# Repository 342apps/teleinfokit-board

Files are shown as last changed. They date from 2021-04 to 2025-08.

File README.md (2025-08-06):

# teleinfokit-board

## Firmware TeleInfoKit

Ce repo comprend les fichiers source Eagle, schema et PCB pour le module de collecte de tele-information [Teleinfokit](https://342apps.net/module-teleinfokit/) associé à son [firmware dédié](https://github.com/342apps/teleinfokit).

Ce module permet de récupérer les données de consommation électrique grâce aux données de télé-information du bus TIC des compteurs électriques français et d'exploiter ces données dans une application de domotique telle que Home Assistant.

## Compatibilité avec ESPHome

Ce module est également compatible avec un firmware généré par [ESPHome](https://esphome.io/) pour une integration dans Home Assistant. 

Le fichier de configuration compatible avec ce module ainsi que toute la documentation est disponible dans le dossier [esphome](./esphome/). Ce firmware offre cependant moins de fonctionnalités que le firmware natif.

## PCB

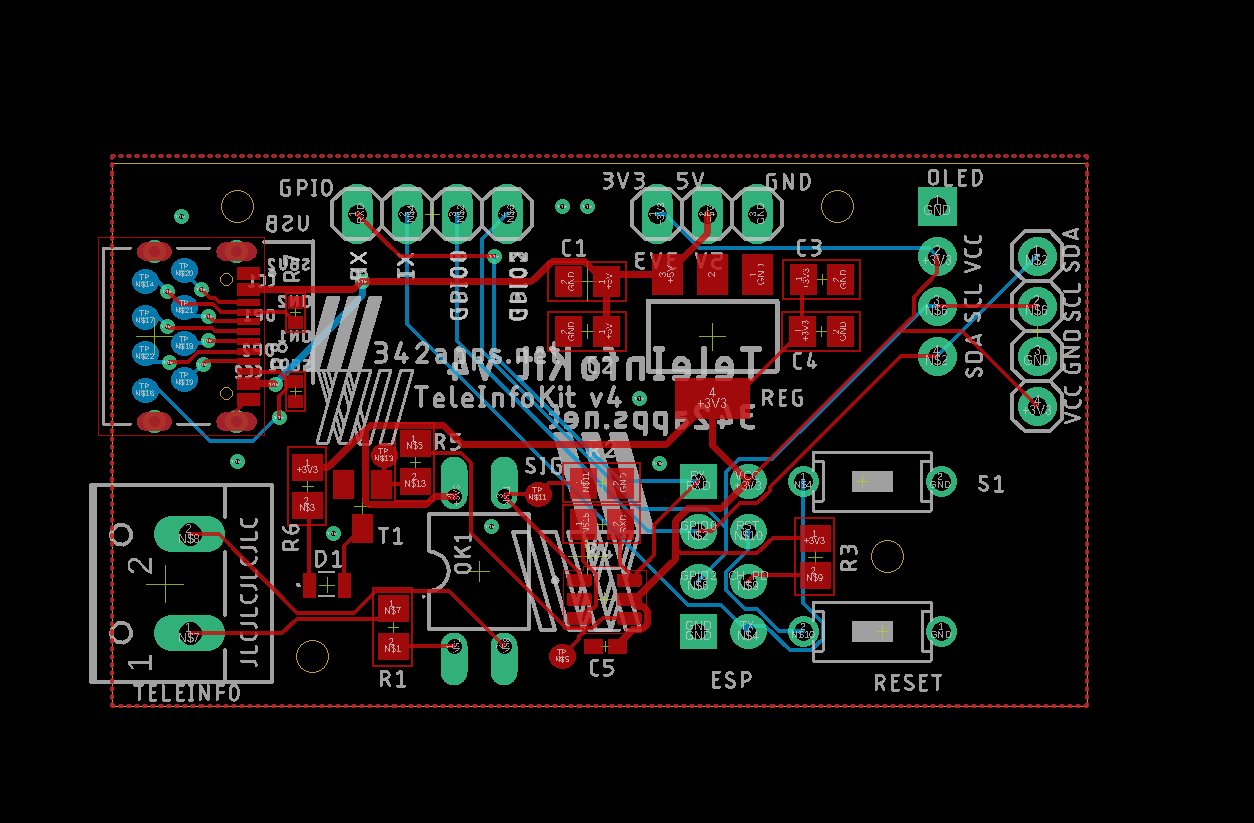
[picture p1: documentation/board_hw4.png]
schema


Fichier source [schematics Eagle](eagle/v4/schematics.sch)

Les versions hardware 3 et 4 sont disponibles dans leurs [répertoires dédiés](/eagle/).

### Gerber files

Toutes les ressources de production générées par Eagle sont dans le dossier [CAMOutputs](CAMOutputs).

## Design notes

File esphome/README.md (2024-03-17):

## Configuration du firmware ESPHome ##
Créez le fichier `secrets.yaml` dans le même répertoire que `teleinfokit_xxx.yaml` pour initialiser les valeurs suivantes :
* `wifi_ssid` : le nom de votre réseau wi-fi
* `wifi_password` : votre clé wi-fi
* `wifi_ap_key` : la clé souhaitée pour le point d'accès qui sera créé si le Teleinfokit ne peut se connecter à votre réseau wi-fi
* `ota_key` : le mot de passe pour les mise à jour via wi-fi
* `api_key` : la clé API souhaitée pour utiliser le TeleInfoKit avec Home-Assistant.

Pour générer une API key unique, sur la [documentation de l'API ESPHOME](https://esphome.io/components/api#configuration-variables) il est possible de générer une clé unique dans votre navigateur. Cette clé est visible dans la section *Configuation variables / Encryption / key*. 

> **Notes** : Si vous souhaitez utiliser le caractère "\\", vous devez en écrire deux.
> 
> Ex : `"mon\\passe"`

## exemple de fichier `secrets.yaml` ##
```yaml
wifi_ssid: "Mon_wifi"
wifi_password: "La clé de mon wi-Fi123"
wifi_ap_key: "givememydata"
api_key: "GvChdo9eznPJMs9z2CSpVnqJzC4E3G6qhnQJx5/A614="
ota_key: "passe_MAJ"
```

## Changer le mot de passe OTA ##
Il n'est pas possible de changer tout simplement le mot de passe dans le fichier secrets.yaml et lancer la mise à jour, puisque le processus de mise à jour OTA se sert du mot de passe configuré pour pouvoir mettre à jour le TeleInfoKit.

Suivez les instruction de [la documentation ESPHome](https://www.esphome.io/components/ota.html#updating-the-password) pour pouvoir changer le mot de passe OTA via une mise à jour OTA.

Pour ceux qui préfèrent des instructions en français :
Dans le bloc `esphome`, rajouter :
```yaml
  on_boot:
    - lambda: |-
        id(my_ota).set_auth_password("New password");
```

Mettez en suite à jour le TeleInfoKit.
Une fois la mise à jour OTA terminée, supprimez les lignes ajoutées précédemment et changez la valeur de `ota_key` dans votre fichier secrets.yaml.

## Configuration avec des fonctionnalités hardware supplémentaires

Une version du firmware avec un capteur de température/pression de type BMP280 sur le même bus I2C que l'écran est disponible également dans ce dossier (`teleinfokit_bmp.yml`). Le capteur est connecté via les pins déportés sur le bord du circuit (SDA : `GPIO0` et SCL : `GPIO2`) pour le bus I2C et l'alimentation par le 3V3 également accessible.

Ce n'est qu'un exemple de ce qui peut être rajouté à l'aide du bus I2C.

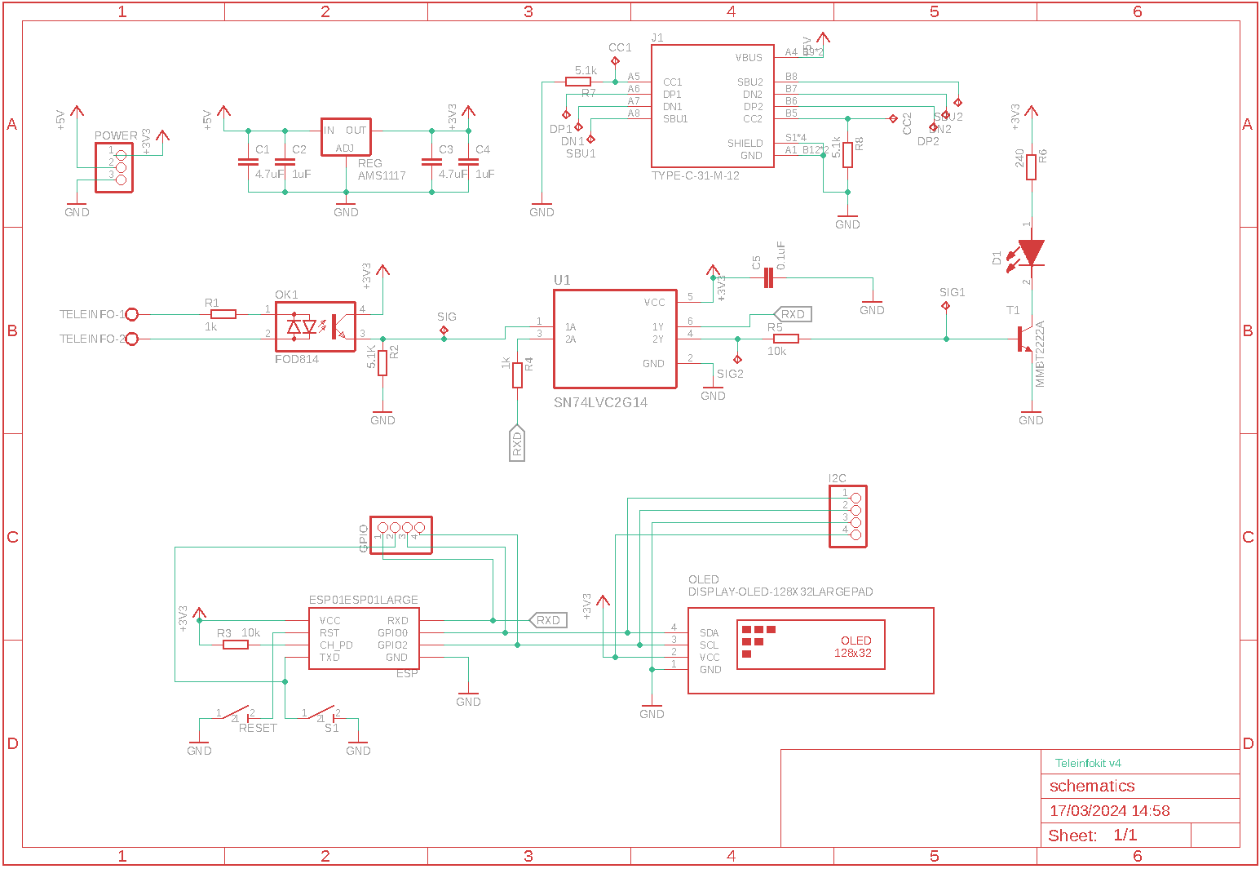
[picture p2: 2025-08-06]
documentation/schematics_hw4.png

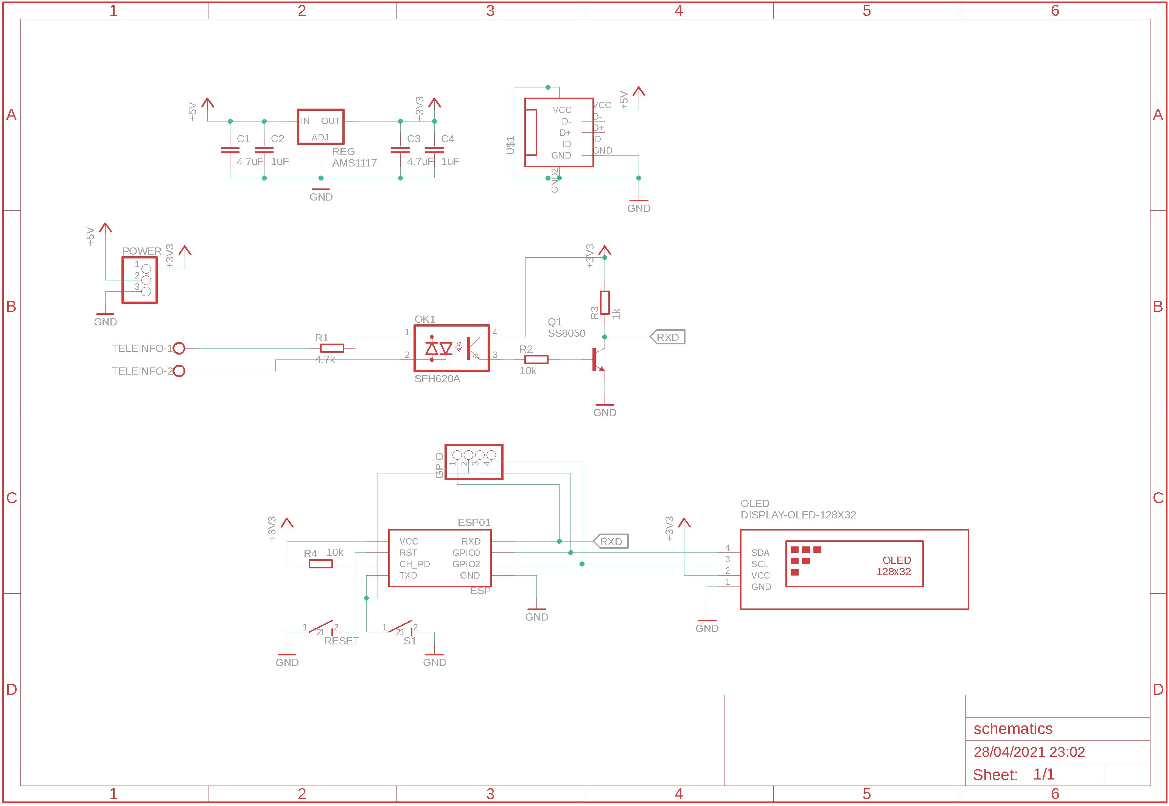
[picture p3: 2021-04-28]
documentation/schematics.png

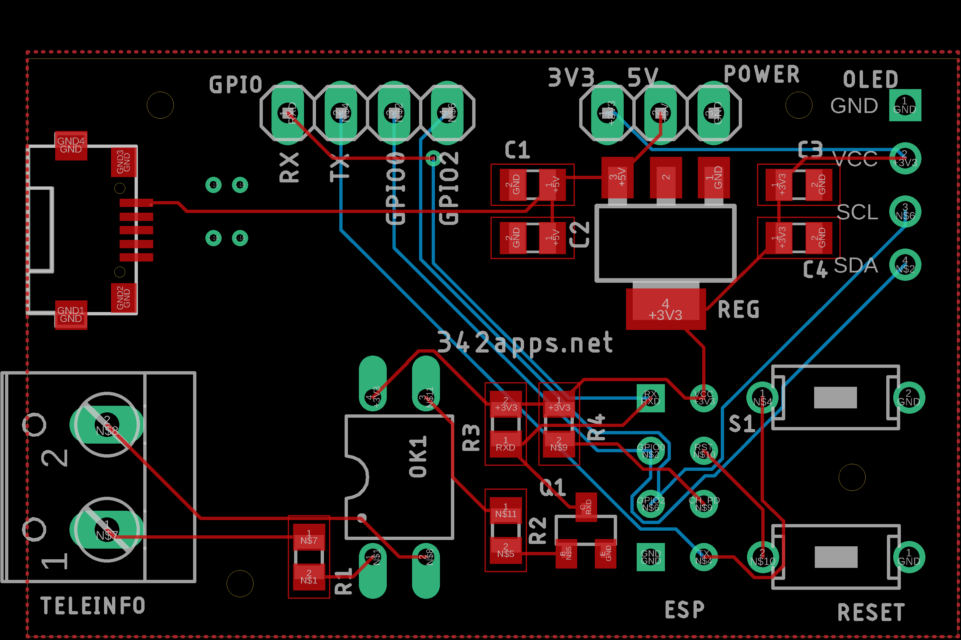
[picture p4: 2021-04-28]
documentation/board.png

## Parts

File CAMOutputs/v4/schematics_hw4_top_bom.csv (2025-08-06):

Comment | Designator | Footprint | LCSC Part #
yellow led | D1 | LED_0805 | C2296
0.1uF | C5 | C0402K | C1525
1k | R1 R4 | R0805 | C17513
1uF | C2 C4 | C0805 | C28323
4.7uF | C1 C3 | C0805 | C1779
5.1k | R2 R7 R8 | R0402 | C25905
10k | R3 R5 | R0805 | C17414
240 | R6 | R0805 | C17572
AMS1117 | REG | SOT223 | C6186
MMBT2222A | T1 | SOT23-BEC | C8512
SN74LVC2G14 | U1 | SOT95P280X145-6N | C12401
TYPE-C-31-M-12 | J1 | HRO_TYPE-C-31-M-12 | C165948

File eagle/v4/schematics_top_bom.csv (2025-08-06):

Comment | Designator | Footprint | LCSC Part #
Yellow | D1 | C0805 | C2296
1k | R1 R4 | R0805 | C17513
1uF | C2 C4 | C0805 | C28323
4.7uF | C1 C3 | C0805 | C1779
0.1uF | C5 | C0402K | C1525
5.1K | R2 | R0603 | C23186
5.1k | R7 R8 | R0402 | C25905
10k | R3 R5 | R0805 | C17414
300 | R6 | R0805 | C17617
AMS1117 | REG | SOT223 | C6186
DISPLAY-OLED-128X32LARGEPAD | OLED | DISPLAY-OLED-128X32LARGE | C2718488
ESP01ESP01LARGE | ESP | ESP01LARGE | C2935984
FOD814 | OK1 | DIL4-SMD | C479718
MMBT2222A | T1 | SOT23-BEC | C8512
SN74LVC2G14 | U1 | SOT95P280X145-6N | C12401
TS-1088-AR02016 | RESET S1 | SW_TS-1088-AR02016 | C720477
TYPE-C-31-M-12 | J1 | HRO_TYPE-C-31-M-12 | C165948

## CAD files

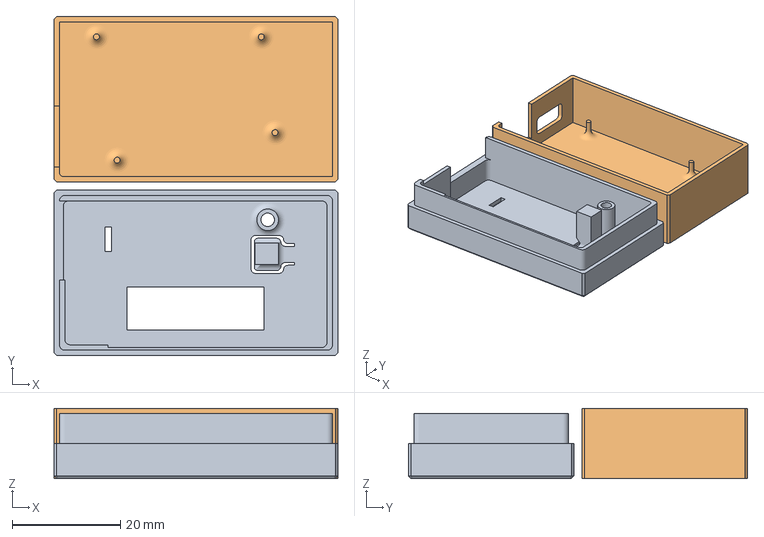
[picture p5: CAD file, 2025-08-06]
3d-model/boitier-teleinfokit-hw4.3mf
52.5 x 62.7 x 13.0 mm
Couvercle.stl
Boitier.stl

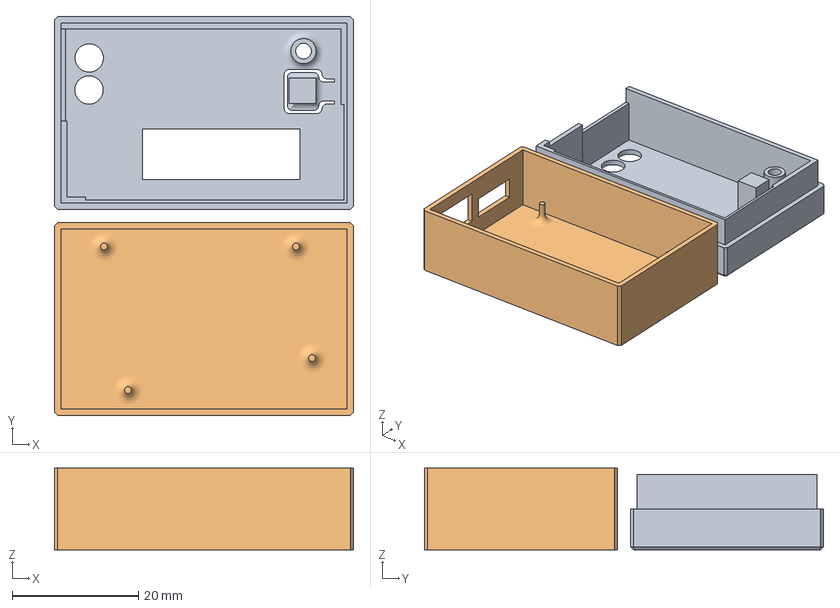
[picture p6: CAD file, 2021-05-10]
3d-model/boitier-teleinfokit-hw2.3mf
47.4 x 63.3 x 13.0 mm
34101f7b-a654-460f-b8fa-4a384699696e.stl
f2c51b2e-c652-4c8d-b341-4edc182d5af4.stl

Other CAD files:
3d-model/boitier-teleinfokit-hw2.stl
3d-model/boitier-teleinfokit-hw4.stl

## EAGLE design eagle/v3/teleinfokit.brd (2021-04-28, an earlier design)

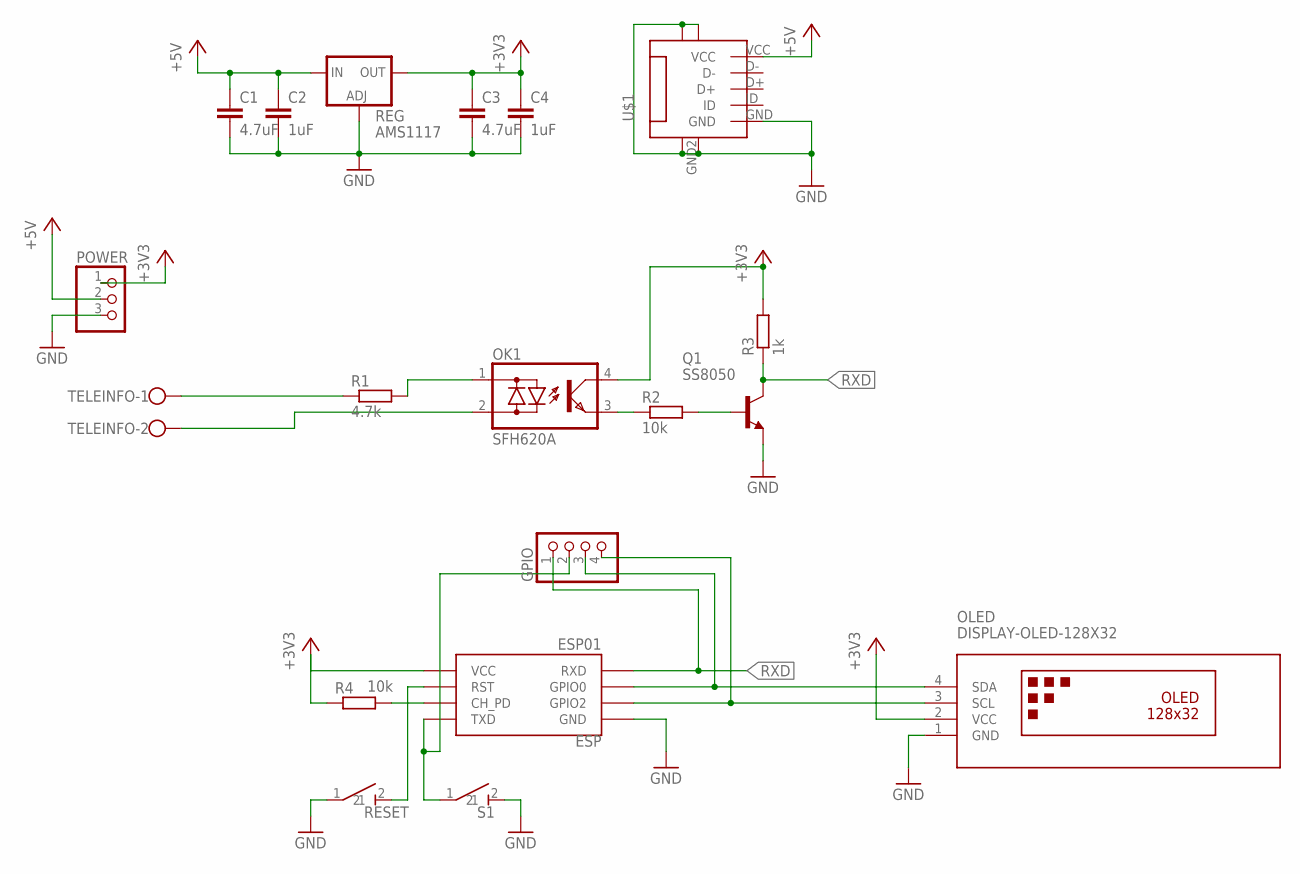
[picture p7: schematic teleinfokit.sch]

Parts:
C1, C3: 4.7uF; C0805; LCSC_PART C1779
C2, C4: 1uF; C0805; LCSC_PART C28323
ESP: ESP01
GPIO: PINHD-1X4; 1X04
OK1: SFH620A; DIL04
OLED: DISPLAY-OLED-128X32
POWER: PINHD-1X3; 1X03
Q1: SS8050; SOT23-BEC; LCSC_PART C2150
R1: 4.7k; R0805; LCSC_PART C17673
R2, R4: 10k; R0805; LCSC_PART C17414
R3: 1k; R0805; LCSC_PART C17513
REG: AMS1117; SOT223; LCSC_PART C6186
RESET: MICROSWITCH
S1: MICROSWITCH
TELEINFO: W237-102
U$1: USB_MICRO_SMD; LCSC_PART C145783

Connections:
+3V3: C3.1, C4.1, ESP.VCC, OK1.4 (C), OLED.2 (VCC), POWER.1, R3.2, R4.1, REG.4 (OUT)
+5V: C1.1, C2.1, POWER.2, REG.3 (IN), U$1.VCC
GND: C1.2, C2.2, C3.2, C4.2, ESP.GND, OLED.1 (GND), POWER.3, Q1.E, REG.1 (ADJ), RESET.1, S1.2, U$1.GND, U$1.GND1, U$1.GND2, U$1.GND3, U$1.GND4
unnamed: OK1.1 (AC1), R1.2
unnamed: ESP.GPIO0, GPIO.3, OLED.4 (SDA)
unnamed: ESP.TX (TXD), GPIO.2, S1.1
unnamed: Q1.B, R2.2
unnamed: ESP.GPIO2, GPIO.4, OLED.3 (SCL)
unnamed: R1.1, TELEINFO.1
unnamed: OK1.2 (AC2), TELEINFO.2
unnamed: ESP.CH_PD, R4.2
unnamed: ESP.RST, RESET.2
unnamed: OK1.3 (E), R2.1
RXD: ESP.RX (RXD), GPIO.1, Q1.C, R3.1

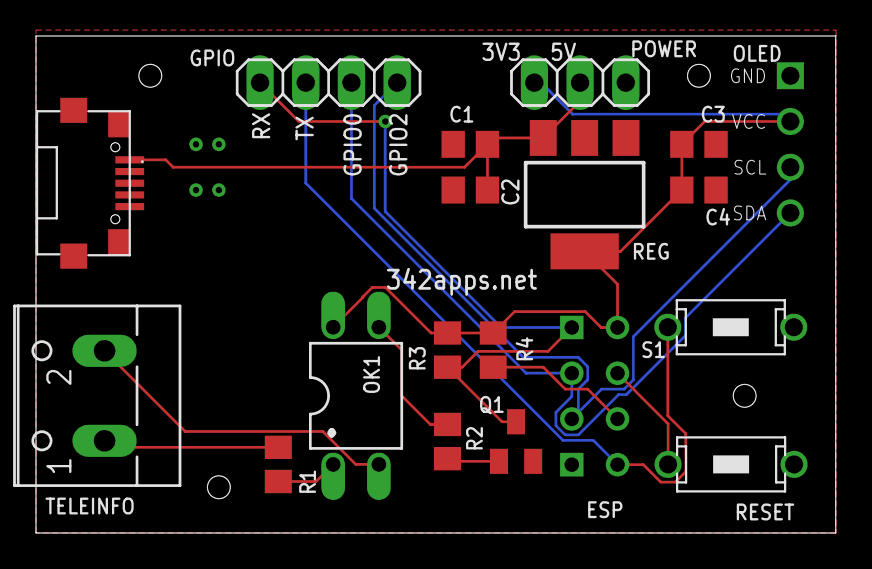
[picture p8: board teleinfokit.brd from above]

Board: 2 copper layers, 44.4 x 27.6 mm, 19 parts (0 on the bottom side), 14 nets.

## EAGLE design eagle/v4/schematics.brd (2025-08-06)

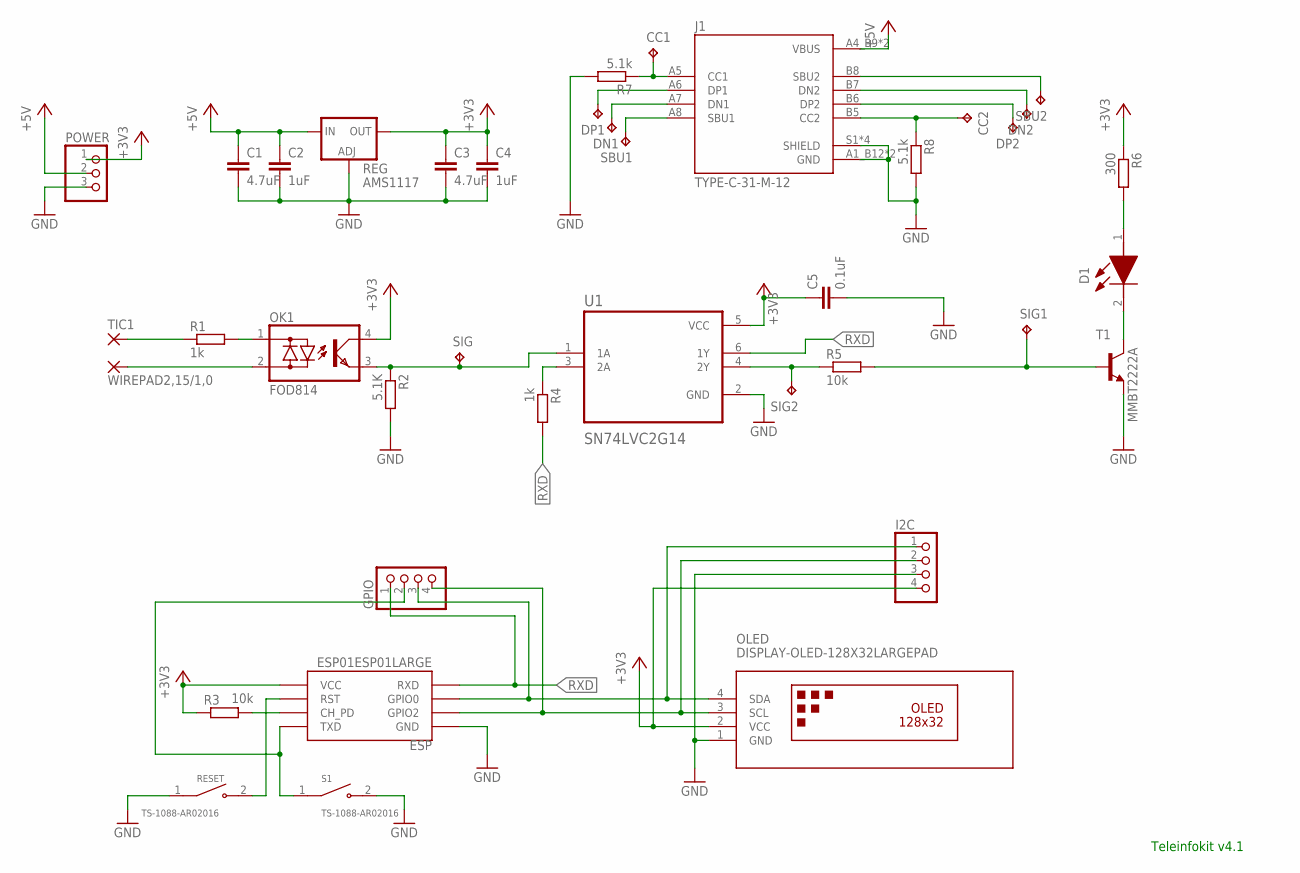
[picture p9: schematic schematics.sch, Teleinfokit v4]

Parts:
C1, C3: 4.7uF; C0805; LCSC_PART C1779
C2, C4: 1uF; C0805; LCSC_PART C28323
C5: 0.1uF; C0402K; LCSC_PART C1525
CC1, CC2: TPB1,27; B1,27
D1: 17-21SURC_S530-A2_TR8; 1721SURCS530A2TR8
DN1, DN2: TPB1,27; B1,27
DP1, DP2: TPB1,27; B1,27
ESP: ESP01ESP01LARGE; ESP01LARGE; LCSC_PART C2935984
GPIO: PINHD-1X4; 1X04
I2C: PINHD-1X4ROUNDLARGE; 1X04ROUNDLARGE
J1: TYPE-C-31-M-12; HRO_TYPE-C-31-M-12; LCSC_PART C165948
OK1: FOD814; DIL4-SMD; LCSC_PART C479718
OLED: DISPLAY-OLED-128X32LARGEPAD; DISPLAY-OLED-128X32LARGE; LCSC_PART C2718488
POWER: PINHD-1X3; 1X03
R1: 1k; R0805; LCSC_PART C17513
R2: 5.1K; R0603; LCSC_PART C23186
R3, R5: 10k; R0805; LCSC_PART C17414
R4: 1k; R0805; LCSC_PART C17414
R6: 300; R0805; LCSC_PART C17617
R7, R8: 5.1k; R0402; LCSC_PART C25905
REG: AMS1117; SOT223; LCSC_PART C6186
RESET: TS-1088-AR02016; SW_TS-1088-AR02016; LCSC_PART C720477
S1: TS-1088-AR02016; SW_TS-1088-AR02016; LCSC_PART C720477
SBU1, SBU2: TPB1,27; B1,27
SIG, SIG1, SIG2: TPB1,27; B1,27
T1: MMBT2222A; SOT23-BEC; LCSC_PART C8512
TIC1, TIC2: WIREPAD2,15/1,0; 2,15/1,0
U1: SN74LVC2G14; SOT95P280X145-6N; LCSC_PART C12401

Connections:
+3V3: C3.1, C4.1, C5.1, ESP.VCC, I2C.4, OK1.4 (C), OLED.2 (VCC), POWER.1, R3.1, R6.1, REG.4 (OUT), U1.5 (VCC)
+5V: C1.1, C2.1, J1.A4_B9 (VBUS), J1.B4_A9 (VBUS), POWER.2, REG.3 (IN)
GND: C1.2, C2.2, C3.2, C4.2, C5.2, ESP.GND, I2C.3, J1.A1_B12 (GND), J1.B1_A12 (GND), J1.S1 (SHIELD), J1.S2 (SHIELD), J1.S3 (SHIELD), J1.S4 (SHIELD), OLED.1 (GND), POWER.3, R2.2, R7.2, R8.2, REG.1 (ADJ), RESET.1, S1.2, T1.E, U1.2 (GND)
unnamed: OK1.1 (AC1), R1.2
unnamed: ESP.GPIO0, GPIO.3, I2C.1, OLED.4 (SDA)
unnamed: D1.1 (A), R6.2
unnamed: ESP.TX (TXD), GPIO.2, S1.1
unnamed: R5.1, SIG2.TP, U1.4 (2Y)
unnamed: ESP.GPIO2, GPIO.4, I2C.2, OLED.3 (SCL)
unnamed: R1.1, TIC1.1
unnamed: OK1.2 (AC2), TIC2.1
unnamed: ESP.CH_PD, R3.2
unnamed: ESP.RST, RESET.2
unnamed: OK1.3 (E), R2.1, SIG.TP, U1.1 (1A)
unnamed: D1.2 (K), T1.C
unnamed: R5.2, SIG1.TP, T1.B
unnamed: CC1.TP, J1.A5 (CC1), R7.1
unnamed: R4.1, U1.3 (2A)
unnamed: CC2.TP, J1.B5 (CC2), R8.1
unnamed: DP1.TP, J1.A6 (DP1)
unnamed: DN1.TP, J1.A7 (DN1)
unnamed: J1.A8 (SBU1), SBU1.TP
unnamed: J1.B8 (SBU2), SBU2.TP
unnamed: DN2.TP, J1.B7 (DN2)
unnamed: DP2.TP, J1.B6 (DP2)
RXD: ESP.RX (RXD), GPIO.1, R4.2, U1.6 (1Y)

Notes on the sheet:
Teleinfokit v4.1

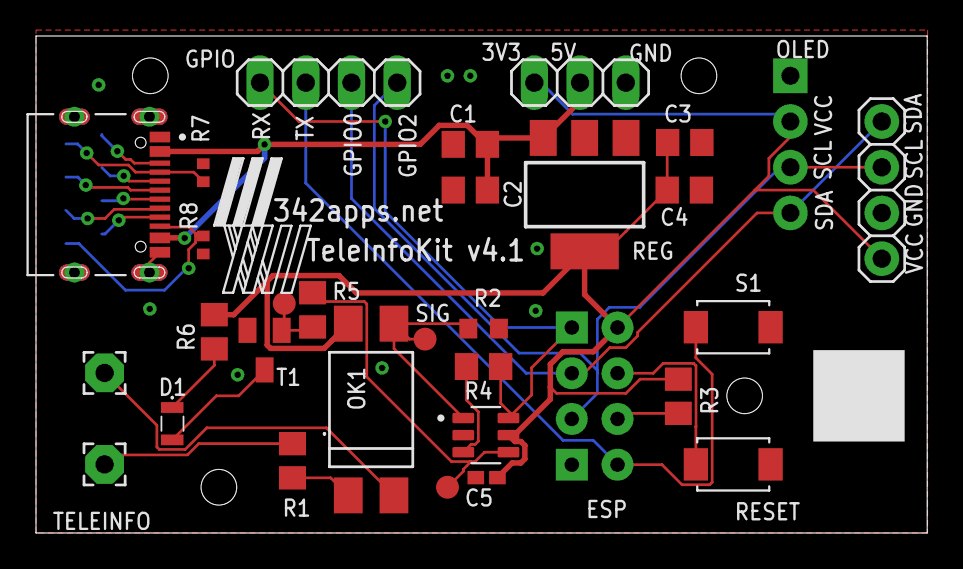
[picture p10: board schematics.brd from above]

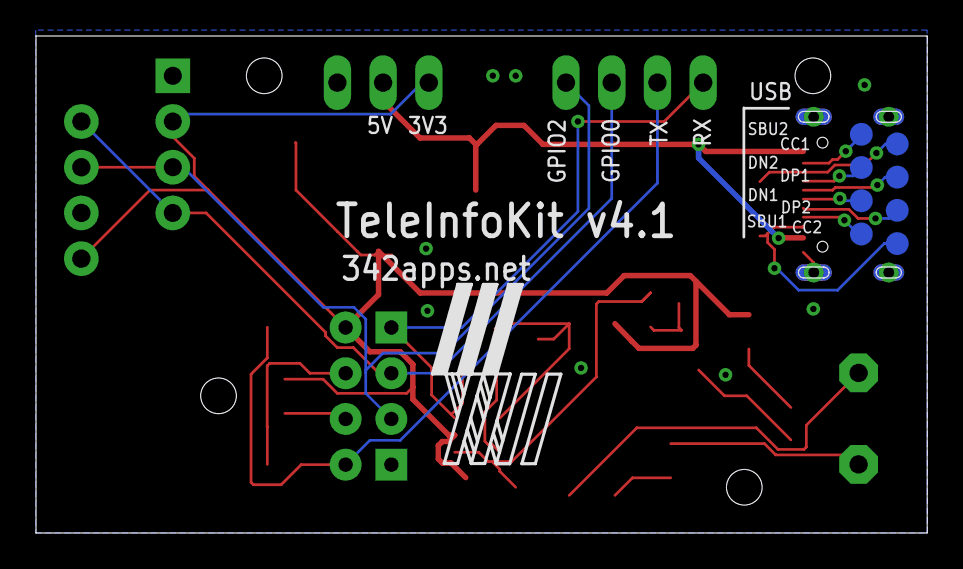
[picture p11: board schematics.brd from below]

Board: 2 copper layers, 49.5 x 27.6 mm, 39 parts (8 on the bottom side), 26 nets.

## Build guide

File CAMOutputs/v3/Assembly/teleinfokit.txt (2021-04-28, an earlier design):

Qty Value               Device              Package             Parts     Description                                                            LCSC_PART MF MPN       OC_FARNELL OC_NEWARK POPULARITY SPICEPREFIX
1                       PINHD-1X3           1X03                POWER     PIN HEADER                                                                                                         92                    
1                       PINHD-1X4           1X04                GPIO      PIN HEADER                                                                                                         91                    
1                       W237-102            W237-102            TELEINFO  WAGO SCREW CLAMP                                                                    237-102   unknown    70K9898   32                    
2   10k                 R-EU_R0805          R0805               R2, R4    RESISTOR, European symbol                                              C17414                                                 R          
1   1k                  R-EU_R0805          R0805               R3        RESISTOR, European symbol                                              C17513                                                 R          
2   1uF                 C-EUC0805           C0805               C2, C4    CAPACITOR, European symbol                                             C28323                                                 C          
1   4.7k                R-EU_R0805          R0805               R1        RESISTOR, European symbol                                              C17673                                                 R          
2   4.7uF               C-EUC0805           C0805               C1, C3    CAPACITOR, European symbol                                             C1779                                                  C          
1   AMS1117             LD117AS33TR         SOT223              REG       Low drop fixed and adjustable positive voltage regulators 1 A          C6186                                                             
1   DISPLAY-OLED-128X32 DISPLAY-OLED-128X32 DISPLAY-OLED-128X32 OLED      128x32 Dot Matrix OLED Module with I2C interface based on SSD1306 chip                                                                   
1   ESP01               ESP01               ESP01               ESP       ESP8266 Wifi module 01                                                                                                                   
2   MICROSWITCH         MICROSWITCH         MICROSWITCH         RESET, S1 basic microswitch                                                                                                                        
1   SFH620A             SFH620A             DIL04               OK1       Optocoupler, Phototransistor Output, AC Input                                       SFH620A-2 1469594    97K9546   1                     
1   SS8050              BC850SMD            SOT23-BEC           Q1        NPN Transistor                                                         C2150                                       1                     
1   USB_MICRO_SMD       USB_MICRO_SMD       USB_MICRO_SMD       U$1                                                                              C145783

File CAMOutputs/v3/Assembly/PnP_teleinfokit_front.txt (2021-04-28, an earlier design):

C1	24.13	21.59	180.00	4.7uF	C0805
C2	24.13	19.05	180.00	1uF	C0805
C3	36.83	21.59	0.00	4.7uF	C0805
C4	36.83	19.05	0.00	1uF	C0805
Q1	26.67	5.08	0.00	SS8050	SOT23-BEC
R1	13.46	3.81	270.00	4.7k	R0805
R2	22.86	5.08	270.00	10k	R0805
R3	22.86	10.16	90.00	1k	R0805
R4	25.40	10.16	270.00	10k	R0805
REG	30.48	18.80	180.00	AMS1117	SOT223
U$1	3.65	19.43	90.00	USB_MICRO_SMD	USB_MICRO_SMD

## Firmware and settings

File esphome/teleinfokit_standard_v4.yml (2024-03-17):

# ESPHome configuration file for teleinfokit module https://342apps.net/module-teleinfokit/
# Configuration pour TIC en mode STANDARD
# Fichier secrets.yaml à créer
# Nouvelle version avec écrans plus complets

esphome:
  name: teleinfokit-std
  friendly_name: teleinfokit-std

esp8266:
  board: esp01_1m

# Enable Home Assistant API
api:
  encryption:
    key: !secret api_key

ota:
  password: !secret ota_key
  
wifi:
  ssid: !secret wifi_ssid
  password: !secret wifi_password

  # Enable fallback hotspot (captive portal) in case wifi connection fails
  ap:
    ssid: "TeleInfoKit-std"
    password: !secret wifi_ap_key

logger:
  baud_rate: 0   # disable logging via UART, help to avoid numerous crash with ESP_LOGD
  level: INFO   # INFO for less log, put DEBUG to view all the linky's "étiquettes" received  in the logs
  esp8266_store_log_strings_in_flash: False     #  :doc:`recommanded for ESP8266 </components/sensor/custom>`

uart:
  id: uart_bus
  rx_pin: GPIO3
  baud_rate: 9600
  parity: EVEN
  data_bits: 7

teleinfo:
  id: myteleinfo
  update_interval: 5s
  historical_mode: false
  uart_id: uart_bus

captive_portal:

image:
  - file: mdi:flash
    id: flash
    resize: 32x32
  - file: mdi:power-plug-outline
    id: plug
    resize: 32x32
  - file: mdi:counter
    id: meter
    resize: 32x32

sensor:
  - platform: teleinfo
    tag_name: "EAST"
    id: EAST
    name: "Energie active soutirée totale"
    unit_of_measurement: "kWh"
    accuracy_decimals: 3
    icon: mdi:flash
    device_class: energy
    state_class: total_increasing
    teleinfo_id: myteleinfo
    filters:
      - multiply: 0.001
  - platform: teleinfo
    tag_name: "EASF01"
    id: EASF01
    name: "Energie active soutirée Fournisseur, index 01"
    unit_of_measurement: "kWh"
    accuracy_decimals: 3
    icon: mdi:flash
    device_class: energy
    state_class: total_increasing
    teleinfo_id: myteleinfo
    filters:
      - multiply: 0.001
  - platform: teleinfo
    tag_name: "EASF02"
    id: EASF02
    name: "Energie active soutirée Fournisseur, index 02"
    unit_of_measurement: "kWh"
    accuracy_decimals: 3
    icon: mdi:flash
    device_class: energy
    state_class: total_increasing
    teleinfo_id: myteleinfo
    filters:
      - multiply: 0.001
  - platform: teleinfo
    tag_name: "EASF03"
    id: EASF03
    name: "Energie active soutirée Fournisseur, index 03"
    unit_of_measurement: "kWh"
    accuracy_decimals: 3
    icon: mdi:flash
    device_class: energy
    state_class: total_increasing
    teleinfo_id: myteleinfo
    filters:
      - multiply: 0.001
  - platform: teleinfo
    tag_name: "EASF04"
    id: EASF04
    name: "Energie active soutirée Fournisseur, index 04"
    unit_of_measurement: "kWh"
    accuracy_decimals: 3
    icon: mdi:flash
    device_class: energy
    state_class: total_increasing
    teleinfo_id: myteleinfo
    filters:
      - multiply: 0.001
  - platform: teleinfo
    tag_name: "EASD01"
    id: EASD01
    name: "Energie active soutirée Distributeur, index 01"
    unit_of_measurement: "kWh"
    accuracy_decimals: 3
    icon: mdi:flash
    device_class: energy
    state_class: total_increasing
    teleinfo_id: myteleinfo
    filters:
      - multiply: 0.001
  - platform: teleinfo
    tag_name: "EASD02"
    id: EASD02
    name: "Energie active soutirée Distributeur, index 02"
    unit_of_measurement: "kWh"
    accuracy_decimals: 3
    icon: mdi:flash
    device_class: energy
    state_class: total_increasing
    teleinfo_id: myteleinfo
    filters:
      - multiply: 0.001
  - platform: teleinfo
    tag_name: "EASD03"
    id: EASD03
    name: "Energie active soutirée Distributeur, index 03"
    unit_of_measurement: "kWh"
    accuracy_decimals: 3
    icon: mdi:flash
    device_class: energy
    state_class: total_increasing
    teleinfo_id: myteleinfo
    filters:
      - multiply: 0.001
  - platform: teleinfo
    tag_name: "EASD04"
    id: EASD04
    name: "Energie active soutirée Distributeur, index 04"
    unit_of_measurement: "kWh"
    accuracy_decimals: 3
    icon: mdi:flash
    device_class: energy
    state_class: total_increasing
    teleinfo_id: myteleinfo
    filters:
      - multiply: 0.001
  - platform: teleinfo
    tag_name: "SINSTS"
    id: SINSTS
    name: "Puissance app. Instantanée soutirée"
    unit_of_measurement: "VA"
    state_class: "measurement"
    icon: mdi:flash
    teleinfo_id: myteleinfo
  - platform: teleinfo
    tag_name: "IRMS1"
    id: IRMS1
    name: "Courant efficace, phase 1"
    unit_of_measurement: "A"
    device_class: current
    state_class: "measurement"
    icon: mdi:flash
    teleinfo_id: myteleinfo
  - platform: teleinfo
    tag_name: "URMS1"
    id: URMS1
    name: "Tension efficace, phase 1"
    unit_of_measurement: "V"
    device_class: voltage
    state_class: "measurement"
    icon: mdi:flash
    teleinfo_id: myteleinfo
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

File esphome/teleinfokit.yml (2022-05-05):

# ESPHome configuration file for teleinfokit module https://342apps.net/module-teleinfokit/

esphome:
  name: teleinfokit
  platform: ESP8266
  board: esp01_1m

wifi:
  ssid: !secret wifi_ssid
  password: !secret wifi_key

  # Enable fallback hotspot (captive portal) in case wifi connection fails
  ap:
    ssid: "TeleInfoKit"
    password: !secret ap_key

captive_portal:

# Enable logging
logger:     
  baud_rate: 0   # disable logging via UART, help to avoid numerous crash with ESP_LOGD
  level: INFO   # INFO for less log, put DEBUG to view all the linky's "étiquettes" received  in the logs
  esp8266_store_log_strings_in_flash: False     #  :doc:`recommanded for ESP8266 </components/sensor/custom>`

# Enable Home Assistant API
api:
  password: !secret api_pass

ota:
  password: !secret ota_pass
  id: my_ota


uart:
  id: uart_bus
  rx_pin: GPIO3
  baud_rate: 1200
  parity: EVEN
  data_bits: 7

teleinfo:
  id: myteleinfo
  update_interval: 30s
  historical_mode: true

sensor:
  - platform: teleinfo
    tag_name: "HCHC"
    id: hchc
    name: "Index Heures Creuses"
    unit_of_measurement: "kWh"
    accuracy_decimals: 3
    icon: mdi:flash
    device_class: energy
    state_class: total_increasing
    teleinfo_id: myteleinfo
    filters:
      - multiply: 0.001
  - platform: teleinfo
    tag_name: "HCHP"
    id: hchp
    name: "Index Heures Pleines"
    unit_of_measurement: "kWh"
    accuracy_decimals: 3
    icon: mdi:flash
    device_class: energy
    state_class: total_increasing
    teleinfo_id: myteleinfo
    filters:
      - multiply: 0.001
  - platform: teleinfo
    tag_name: "BASE"
    id: base
    name: "Index Base"
    unit_of_measurement: "kWh"
    accuracy_decimals: 3
    icon: mdi:flash
    device_class: energy
    state_class: total_increasing
    teleinfo_id: myteleinfo
    filters:
      - multiply: 0.001
  - platform: teleinfo
    tag_name: "PAPP"
    id: papp
    name: "Puissance Actuelle"
    unit_of_measurement: "VA"
    state_class: "measurement"
    icon: mdi:flash
    teleinfo_id: myteleinfo
  - platform: teleinfo
    tag_name: "IINST"
    id: iinst
    name: "Intensité Actuelle"
    unit_of_measurement: "A"
    device_class: current
    state_class: "measurement"
    icon: mdi:flash
    teleinfo_id: myteleinfo

i2c:
  sda: GPIO0
  scl: GPIO2

font:
  - file: "arial.ttf"
    id: arial_font
    size: 16

display:
  - platform: ssd1306_i2c
    model: "SSD1306 128x32"
    id: oled
    rotation: 180°
    address: 0x3C
    pages:
      - id: page1
        lambda: |-
          it.printf(0, 0, id(arial_font), "Conso: %.0f VA", id(papp).state);
      - id: page2
        lambda: |-
          it.printf(0, 0, id(arial_font), "Intensite: %.0f A", id(iinst).state);
      - id: page3
        lambda: |-
          it.printf(0, 0, id(arial_font), "HP: %.0f", id(hchp).raw_state);
      - id: page4
        lambda: |-
          it.printf(0, 0, id(arial_font), "HC: %.0f", id(hchc).raw_state);
      - id: page5
        lambda: |-
          it.printf(0, 0, id(arial_font), "BASE: %.0f", id(base).raw_state);

interval:
  - interval: 2s
    then:
      - display.page.show_next: oled
      - component.update: oled

binary_sensor:
  - platform: gpio
    pin:
      number: GPIO1
      mode: INPUT_PULLUP
      inverted: True
    name: teleinfokit_switch
    internal: true
    on_click:
      min_length: 50ms
      max_length: 350ms
      then:
        - lambda: if (id(oled).is_on()) id(oled).turn_off(); else id(oled).turn_on();

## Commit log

2021-04-28 Added board resources
    [teleinfokit.brd, teleinfokit.sch]
2021-04-28 Added gerber files
    [copper_bottom.gbr, copper_top.gbr, drill_1_16.xln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]
2021-05-03 turn screen on and off with button
2021-05-10 Added 3d models
    [boitier-teleinfokit-hw2.3mf, boitier-teleinfokit-hw2.stl]
2021-07-28 Improve ESPHome firmware
    * Use secrets.yaml to store sensitive data
    * Change sensors name to have them in French
    * Add a documentation to list secret.yaml values and give some tips
2021-08-21 Update README.md
    fix orthographe et guillemet dans la doc
2021-08-21 Add classes to sensors
    * State class to specify it is a measurement sensor
    * device_class to specify it is an energy sensor
    After more configuration on Home-Assistant side, it could allow to use these sensors with energy integration from Home-Assistant 2021.8
2021-09-24 Mark the teleinfokit_switch binary sensor internal
    As it is used for the physical button, it is not needed to display it for API
    Note: for existting installations in Home Assistant, it will make the previously added entity as orphan and the Delete button looks unavailable.
2021-09-24 Add classes to directly integrate sensors to HA energy dashboard
2021-09-24 Convert sensors data to kWh
    It makes integration easyer to Home Assistant energy dashboard, avoiding to create template sensors in Home Assistant where conversion would be made.
    In this way utility meters can be directly sourced by ESPHome sensors.
    Decimals are displayed to have the most precize measures.
    [teleinfokit.yml]
2021-09-24 Do not apply fiter on the display device
2021-09-24 Appy last changes to example with bmp sensor
2021-09-26 Change filter in kWh conversion
    I forgot to submit something in #6 when converting to kWh
    As multiply is native to ESPHome and has the same result we have now, there is no reason to use a lambda filter.
2021-12-02 Fichier de configuration pour modules sans écran
2024-03-17 Hardware for version 4
    [boitier-teleinfokit-hw4.3mf, boitier-teleinfokit-hw4.stl, schematics.brd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]
2025-07-24 update v4
    [schematics_top_bom.csv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]

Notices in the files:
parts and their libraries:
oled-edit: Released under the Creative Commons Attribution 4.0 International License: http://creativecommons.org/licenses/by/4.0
